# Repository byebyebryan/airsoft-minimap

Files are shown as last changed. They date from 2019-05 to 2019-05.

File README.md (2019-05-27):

# Rail Mountable MiniMap Display for Airsoft

## Concept

This project is the real life implementation of the mini-maps commonly seen in FPS shooters. The main target is to increase BSA in airsoft games by showing real-time position of friendlies and POIs.

The core part of the project is to exchange GPS positions via LR radio links (>500m).

## Microcontroller

I chose the Adafruit M0 mostly for the integrated RFM69 radio. It is quite a bit more expensive than Arduino Mini/Nano boards but to be honest I think the ATmega chips with limited RAM are gonna have hard times driving the display.

## Radio

Possible options:

* HC-12 433Mhz, TTL interface
* NRF24L01+ 2.4Ghz, SPI interface
* RFM69 433/868/915Mhz, SPI interface

## Rail Mountable Case

I've played with some designs regarding the case. The one with the angled mount clips onto the top rail so is the most straight forward one. If it's a gun with side rails the side mount is also a good option. Worst case scenario there is the one without mounts and you just duct tape the case on.

## Code

I'm no expert in embedded systems coding but here are what I found:

Biggest problem is the radio talks half-duplex, which means if two radio transmits at the same time, everything gets gobbled up and nothing gets through. So every node needs to wait for its turn to transmit, and every node need to sync with each other so it knows when is its turn.

Another problem is I suspect the radio doesn't buffer on the receiving side(not sure about this though, but let's assume the worst just to be safe). So when any other node starts transmitting, it better be listening, otherwise it won't get the message. However, the radio share the SPI bus with the screen, and drawing on screen actually can take quite a bit of time (fill the whole screen can take ~100ms). So we need to plan out when we are transmitting, when we are receiving, and when to draw stuff on the screen.

For a 2 node scenario, a possible solution work like this:

* Loop starts at 0ms;
* The node transmits for a few times, with the send time within the messages;
* In between transmissions (which are really quick), refresh part of the screen;
* The whole transmission phase should only take ~100ms;
* Wait till 500ms since loop start;
* Listen for 200ms for the other node's messages;
* Sync with the other node by comparing the received time and the ref time within the messages
* Wait till 1000ms since loop start, factor in the sync correction, and start the new loop

## Libraries

[Adafruit RadioHead fork](https://github.com/adafruit/RadioHead)

[Adafruit SSD1351](https://github.com/adafruit/Adafruit-SSD1351-library)

[Adafruit HMC5883](https://github.com/adafruit/Adafruit_HMC5883_Unified)

[TinyGPSPlus](https://github.com/mikalhart/TinyGPSPlus)

## Components

[Adafruit Feather M0 Radio with RFM69 Packet Radio](https://learn.adafruit.com/adafruit-feather-m0-radio-with-rfm69-packet-radio/overview)

[Beitian BN-880 Flight Control GPS Module Dual Module Compass](https://www.banggood.com/UBLOX-NEO-M8N-BN-880-Flight-Control-GPS-Module-Dual-Module-Compass-p-971082.html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)

[Waveshare 1.5inch RGB OLED Module](https://www.waveshare.com/wiki/1.5inch_RGB_OLED_Module)

[Luxtude myColors 3350mAh Small Power Bank](https://www.amazon.ca/Luxtude-myColors-Nintendo-Portable-Lipstick/dp/B07MT8J4B5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)

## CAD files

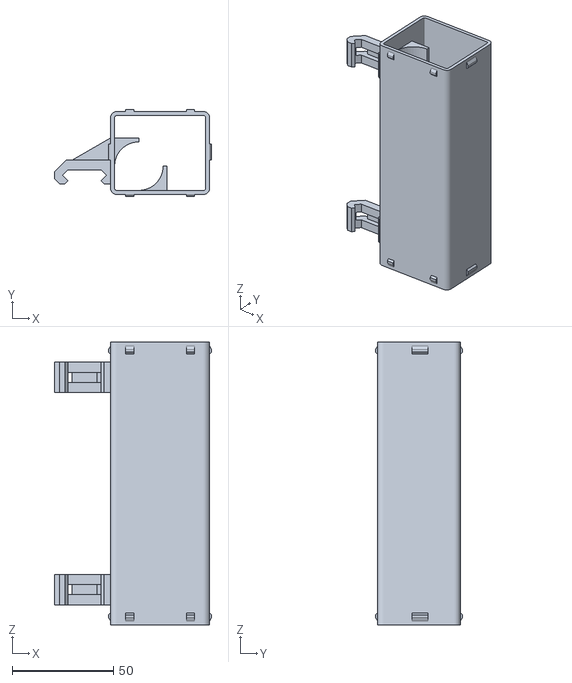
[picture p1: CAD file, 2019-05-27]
case/full-body-w-angle-mounts.stl
77.8 x 43.0 x 140.0

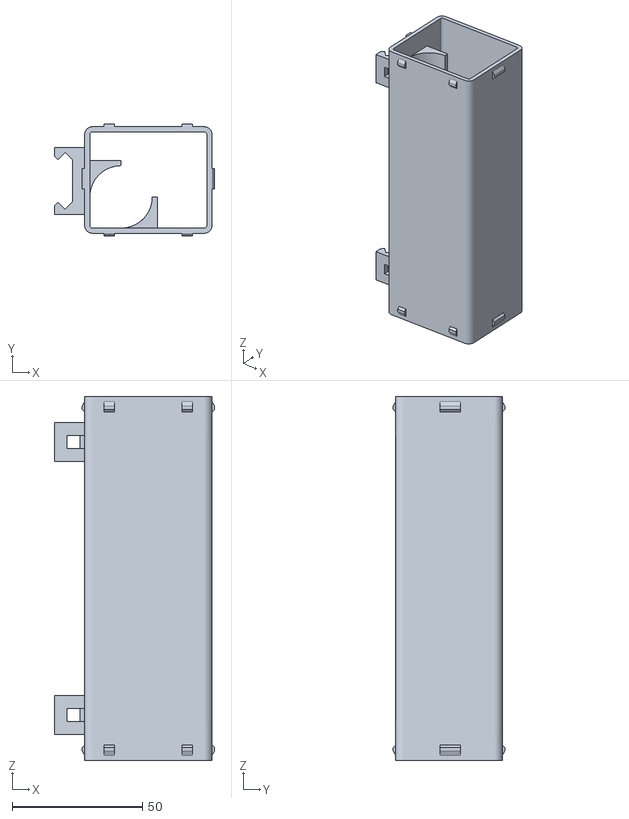
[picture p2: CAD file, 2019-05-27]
case/full-body-w-side-mounts.stl
61.7 x 43.0 x 140.0

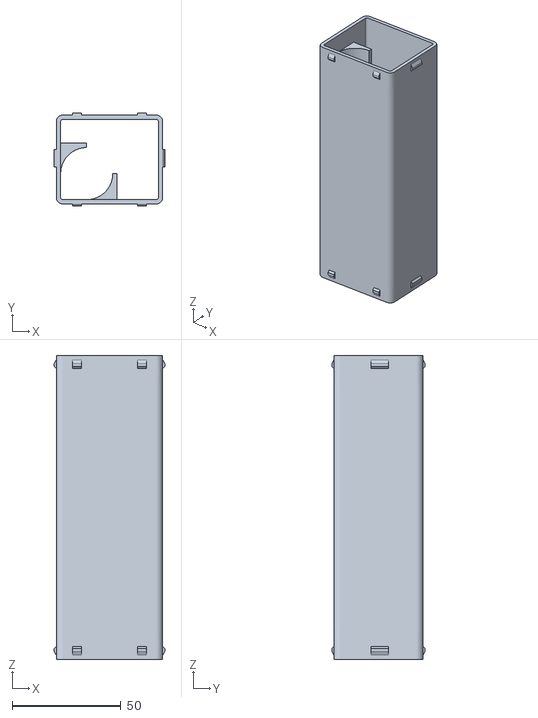
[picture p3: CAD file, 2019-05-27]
case/full-body-wo-mounts.stl
51.0 x 43.0 x 140.0

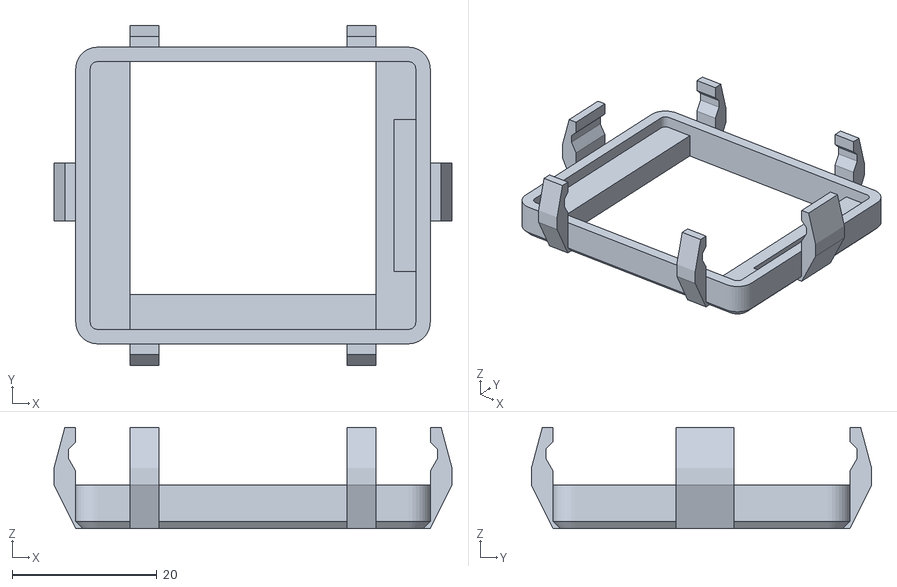
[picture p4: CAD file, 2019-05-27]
case/front-cover.stl
55.0 x 47.0 x 14.0

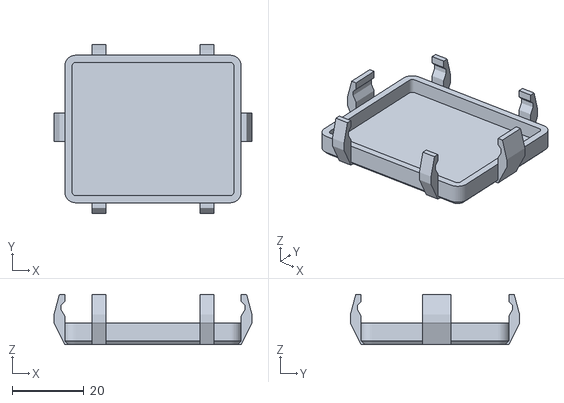
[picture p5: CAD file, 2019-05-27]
case/back-cover.stl
55.0 x 47.0 x 14.0

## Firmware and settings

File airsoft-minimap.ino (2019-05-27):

// rf69 demo tx rx.pde
// -*- mode: C++ -*-
// Example sketch showing how to create a simple messageing client
// with the RH_RF69 class. RH_RF69 class does not provide for addressing or
// reliability, so you should only use RH_RF69  if you do not need the higher
// level messaging abilities.
// It is designed to work with the other example rf69_server.
// Demonstrates the use of AES encryption, setting the frequency and modem 
// configuration

#include <SPI.h>

#include <Adafruit_GFX.h>
#include <Adafruit_SSD1351.h>

#include <RH_RF69.h>

#include <TinyGPS++.h>

#include <Wire.h>
#include <Adafruit_Sensor.h>
#include <Adafruit_HMC5883_U.h>

#include "MiniMap.h"

// Screen dimensions
#define SCREEN_WIDTH  128
#define SCREEN_HEIGHT 128 // Change this to 96 for 1.27" OLED.

// You can use any (4 or) 5 pins 
#define SCLK_PIN 24
#define MOSI_PIN 23
#define CS_PIN   17
#define DC_PIN   18
#define RST_PIN  19

// Color definitions
#define BLACK           0x0000
#define BLUE            0x001F
#define RED             0xF800
#define GREEN           0x07E0
#define CYAN            0x07FF
#define MAGENTA         0xF81F
#define YELLOW          0xFFE0  
#define WHITE           0xFFFF
#define GRAY            0x8410

/************ Dispay Setup ***************/

Adafruit_SSD1351 tft = Adafruit_SSD1351(SCREEN_WIDTH, SCREEN_HEIGHT, &SPI, CS_PIN, DC_PIN, RST_PIN);

/************ GPS Setup ***************/

#define GPSSerial Serial1

static const uint32_t GPSBaud = 9600;

TinyGPSPlus gps;

/************ Mag Setup ***************/

Adafruit_HMC5883_Unified mag = Adafruit_HMC5883_Unified(12345);

/************ Radio Setup ***************/

// Change to 434.0 or other frequency, must match RX's freq!
#define RF69_FREQ 915.0


#define RFM69_CS      8
#define RFM69_INT     3
#define RFM69_RST     4
#define LED           13


// Singleton instance of the radio driver
RH_RF69 rf69(RFM69_CS, RFM69_INT);

int16_t packetnum = 0;  // packet counter, we increment per xmission

/************ End Setup ***************/

uint8_t id = 1;

float heading = 0.0;
float declinationAngle = 0.1827;

Node other;

uint8_t buf[RH_RF69_MAX_MESSAGE_LEN];
uint8_t len = sizeof(buf);

void setup() 
{
  Serial.begin(115200);
  //while (!Serial) { delay(1); } // wait until serial console is open, remove if not tethered to computer

  /************ Dispay Init ***************/
  
  tft.begin();
  tft.fillScreen(BLACK);

  /************ GPS Init ***************/

  GPSSerial.begin(GPSBaud);

  /************ Mag Init ***************/

  if(!mag.begin())
  {
    /* There was a problem detecting the HMC5883 ... check your connections */
    Serial.println("Ooops, no HMC5883 detected ... Check your wiring!");
  }
  
  /************ Radio Init ***************/

  pinMode(LED, OUTPUT);     
  pinMode(RFM69_RST, OUTPUT);
  digitalWrite(RFM69_RST, LOW);

  // manual reset
  digitalWrite(RFM69_RST, HIGH);
  delay(10);
  digitalWrite(RFM69_RST, LOW);
  delay(10);
  
  if (!rf69.init()) {
    Serial.println("RFM69 radio init failed");
    while (1);
  }
  Serial.println("RFM69 radio init OK!");
  // Defaults after init are 434.0MHz, modulation GFSK_Rb250Fd250, +13dbM (for low power module)
  // No encryption
  if (!rf69.setFrequency(RF69_FREQ)) {
    Serial.println("setFrequency failed");
  }

  // If you are using a high power RF69 eg RFM69HW, you *must* set a Tx power with the
  // ishighpowermodule flag set like this:
  rf69.setTxPower(20, true);  // range from 14-20 for power, 2nd arg must be true for 69HCW

  // The encryption key has to be the same as the one in the server
  uint8_t key[] = { 0x01, 0x02, 0x03, 0x04, 0x05, 0x06, 0x07, 0x08,
                    0x01, 0x02, 0x03, 0x04, 0x05, 0x06, 0x07, 0x08};
  rf69.setEncryptionKey(key);
  
  pinMode(LED, OUTPUT);
  digitalWrite(LED,LOW);

  Serial.print("RFM69 radio @");  Serial.print((int)RF69_FREQ);  Serial.println(" MHz");

  /************ End Init ***************/

  tft.fillScreen(BLACK);

  uint32_t loop_start = millis();
  while(millis() < loop_start + 1000) {
    if (rf69.available())  { 
      // Should be a reply message for us now   
      if (rf69.recv(buf, &len)) {
        Msg msg = parseMsg(buf, 12);
        updateNode(other, msg);
        delay(500 - msg.ref_time);
        break;
      } else {
        Serial.println("Receive failed");
      }
    }
  }
}

void loop() {
  uint32_t loop_start = millis();
  int w = tft.width(), h = tft.height();

  Serial.print("Start: "); Serial.println(loop_start);

  readGPS();
  readHeading();

  tft.setCursor(0,0);
  tft.setTextColor(WHITE);
  tft.setTextSize(1);

  digitalWrite(LED,HIGH);
  for(int i=0; i<4; i++){
    prepareMsg(buf, 1, id, millis()- loop_start, heading, gps.location.lat(), gps.location.lng());
    rf69.send(buf, 12);
    rf69.waitPacketSent();
    delay(loop_start + (i+1)*25 - millis());
  }
  digitalWrite(LED,LOW);

  Serial.print("Sent: "); Serial.println(millis());

  for(int i=0; i<4; i++){
    tft.fillRect(0,i*h/4,w,h/4,BLACK);
    if(i == 0){
      tft.print("Lat: "); tft.println(gps.location.lat(), 2);
      tft.print("Lon: "); tft.println(gps.location.lng(), 2); 
      tft.print("Hdg: "); tft.println((uint16_t)heading); 
    }
    // if(i == 1){
    //   tft.setCursor(0,32);
    //   tft.setTextColor(YELLOW);
    //   tft.print("Lat: "); tft.println(other.lat, 4);
    //   tft.print("Lon: "); tft.println(other.lng, 4); 
    //   tft.print("Heading: "); tft.println(other.hdg); 
    // }
  }

  drawCross(63, 63, 8, WHITE);
  tft.drawCircle(64, 64, 51, GRAY);
  tft.drawCircle(64, 64, 26, GRAY);

  if(gps.location.isValid()){
    int x, y, d;
    getRelativePos(500, 43.764052, -79.407043, x, y, d);

    drawCross(63+x, 63+y, 8, GREEN);
    tft.setCursor(63+x+4, 63+y+4);
    tft.setTextColor(GREEN);
    tft.print(d);
  } 

  if(gps.location.isValid() && loop_start - other.last_recv < 5000 && abs(other.lat) > 0.1 && abs(other.lng) > 0.1){
    int x, y, d;
    getRelativePos(500, other.lat, other.lng, x, y, d);

    drawCross(63+x, 63+y, 8, YELLOW);
    tft.setCursor(63+x+4, 63+y+4);
    tft.setTextColor(YELLOW);
    tft.print(d);
  }

  delay(loop_start + 500 - millis());
  Serial.print("Drawn: "); Serial.println(millis());

  while(millis() < loop_start + 1000) {
    if (rf69.available())  { 
      // Should be a reply message for us now   
      if (rf69.recv(buf, &len)) {
        Msg msg = parseMsg(buf, 12);
        updateNode(other, msg);
        loop_start = msg.recv_at - msg.ref_time - 500;
        Serial.print("Recv Lat: "); Serial.print(other.lat, 4);
        Serial.print(", Lon: "); Serial.println(other.lng, 4); 
      } else {
        Serial.println("Receive failed");
      }
    }
  }
}

void drawCross(int x, int y, int s, uint16_t color){
  tft.drawFastHLine(x-s+1, y, s*2, color);
  tft.drawFastHLine(x-s+1, y+1, s*2, color);
  tft.drawFastVLine(x, y-s+1, s*2, color);
  tft.drawFastVLine(x+1, y-s+1, s*2, color);
}

void getRelativePos(int max_d, float lat, float lng, int& x, int& y, int& d){
  float dis = TinyGPSPlus::distanceBetween(gps.location.lat(), gps.location.lng(), lat, lng);
  float crs = TinyGPSPlus::courseTo(gps.location.lat(), gps.location.lng(), lat, lng);

  x = (int)(sin(radians(crs)) * dis * 64 / max_d);
  y = -(int)(cos(radians(crs)) * dis * 64 / max_d);
  d = (int)dis;
}

void readGPS() {
  int l = GPSSerial.available();
  for(int i=0; i< l; i++){
    gps.encode(GPSSerial.read());
  }
  Serial.print("GPS Read bytes: "); Serial.println(l);
  Serial.print("Sat: "); Serial.print(gps.satellites.value());
  Serial.print(", HDop: "); Serial.print(gps.hdop.hdop(), 4);
  Serial.print(", Lat: "); Serial.print(gps.location.lat(), 4);
  Serial.print(", Lon: "); Serial.println(gps.location.lng(), 4); 
}

void readHeading() {
  sensors_event_t event; 
  mag.getEvent(&event);
 
  /* Display the results (magnetic vector values are in micro-Tesla (uT)) */
  // Serial.print("X: "); Serial.print(event.magnetic.x); Serial.print("  ");
  // Serial.print("Y: "); Serial.print(event.magnetic.y); Serial.print("  ");
  // Serial.print("Z: "); Serial.print(event.magnetic.z); Serial.print("  ");Serial.println("uT");

  // Hold the module so that Z is pointing 'up' and you can measure the heading with x&y
  // Calculate heading when the magnetometer is level, then correct for signs of axis.
  heading = atan2(event.magnetic.y, event.magnetic.x);
  
  // Once you have your heading, you must then add your 'Declination Angle', which is the 'Error' of the magnetic field in your location.
  // Find yours here: http://www.magnetic-declination.com/
  // Mine is: -13* 2' W, which is ~13 Degrees, or (which we need) 0.22 radians
  // If you cannot find your Declination, comment out these two lines, your compass will be slightly off.
  heading += declinationAngle;
  
  // Correct for when signs are reversed.
  if(heading < 0)
    heading += 2*PI;
    
  // Check for wrap due to addition of declination.
  if(heading > 2*PI)
    heading -= 2*PI;
   
  // Convert radians to degrees for readability.
  heading = heading * 180/M_PI; 
  
  Serial.print("Heading: "); Serial.println(heading);
}

void Blink(byte PIN, byte DELAY_MS, byte loops) {
  for (byte i=0; i<loops; i++)  {
    digitalWrite(PIN,HIGH);
    delay(DELAY_MS);
    digitalWrite(PIN,LOW);
    delay(DELAY_MS);
  }
}
